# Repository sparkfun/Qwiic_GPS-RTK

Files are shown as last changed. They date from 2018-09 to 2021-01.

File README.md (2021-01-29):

SparkFun Ublox GPS-RTK (Qwiic) - NEO-M8P-2
===========================================================

SparkFun GPS-RTK - NEO-M8P-2 (https://www.sparkfun.com/products/15005)

[*SparkFun GPS-RTK - NEO-M8P-2 (GPS-15005)*](https://www.sparkfun.com/products/15005)

The NEO-M8P-2 module is the top-of-the-line module for high accuracy GNSS and GPS location solutions including RTK. The NEO-M8P-2 is unique in that it is capable of both rover and base station operations. The ‘-2’ designation means this module has survey-in mode allowing the module to become a base station and produce RTCM 3.x correction data. 

Repository Contents
-------------------

* **/Documents** - Ublox datasheets and various whitepapers around RTK
* **/Hardware** - Eagle files

Documentation
--------------

* **[Installing an Arduino Library Guide](https://learn.sparkfun.com/tutorials/installing-an-arduino-library)** - Basic information on how to install an Arduino library.
* **[Arduino Library](https://github.com/sparkfun/SparkFun_u-blox_GNSS_Arduino_Library)** - Arduino Library for the SparkFun Ublox GPS-RTK.
* **[Hookup Guide](https://learn.sparkfun.com/tutorials/gps-rtk-hookup-guide)** - Basic hookup guide for the SparkFun Ublox GPS-RTK.

Product Versions
----------------
* [GPS-15005](https://www.sparkfun.com/products/15005) - SparkFun Red
* [SPX-14980](https://www.sparkfun.com/products/14980) - SparkX Black

License Information
-------------------

This product is _**open source**_! 

Various bits of the code have different licenses applied. Anything SparkFun wrote is beerware; if you see me (or any other SparkFun employee) at the local, and you've found our code helpful, please buy us a round!

Please use, reuse, and modify these files as you see fit. Please maintain attribution to SparkFun Electronics and release anything derivative under the same license.

Distributed as-is; no warranty is given.

- Your friends at SparkFun.

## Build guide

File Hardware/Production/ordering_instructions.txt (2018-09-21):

panel size, 96x88mm
PCB thickness, 1.6mm
number of layers, 2
soldermask color, Red
silkscreen color, White
oz copper, 1oz
finish, HASL lead free
stencils, top
pcs per panel, 4

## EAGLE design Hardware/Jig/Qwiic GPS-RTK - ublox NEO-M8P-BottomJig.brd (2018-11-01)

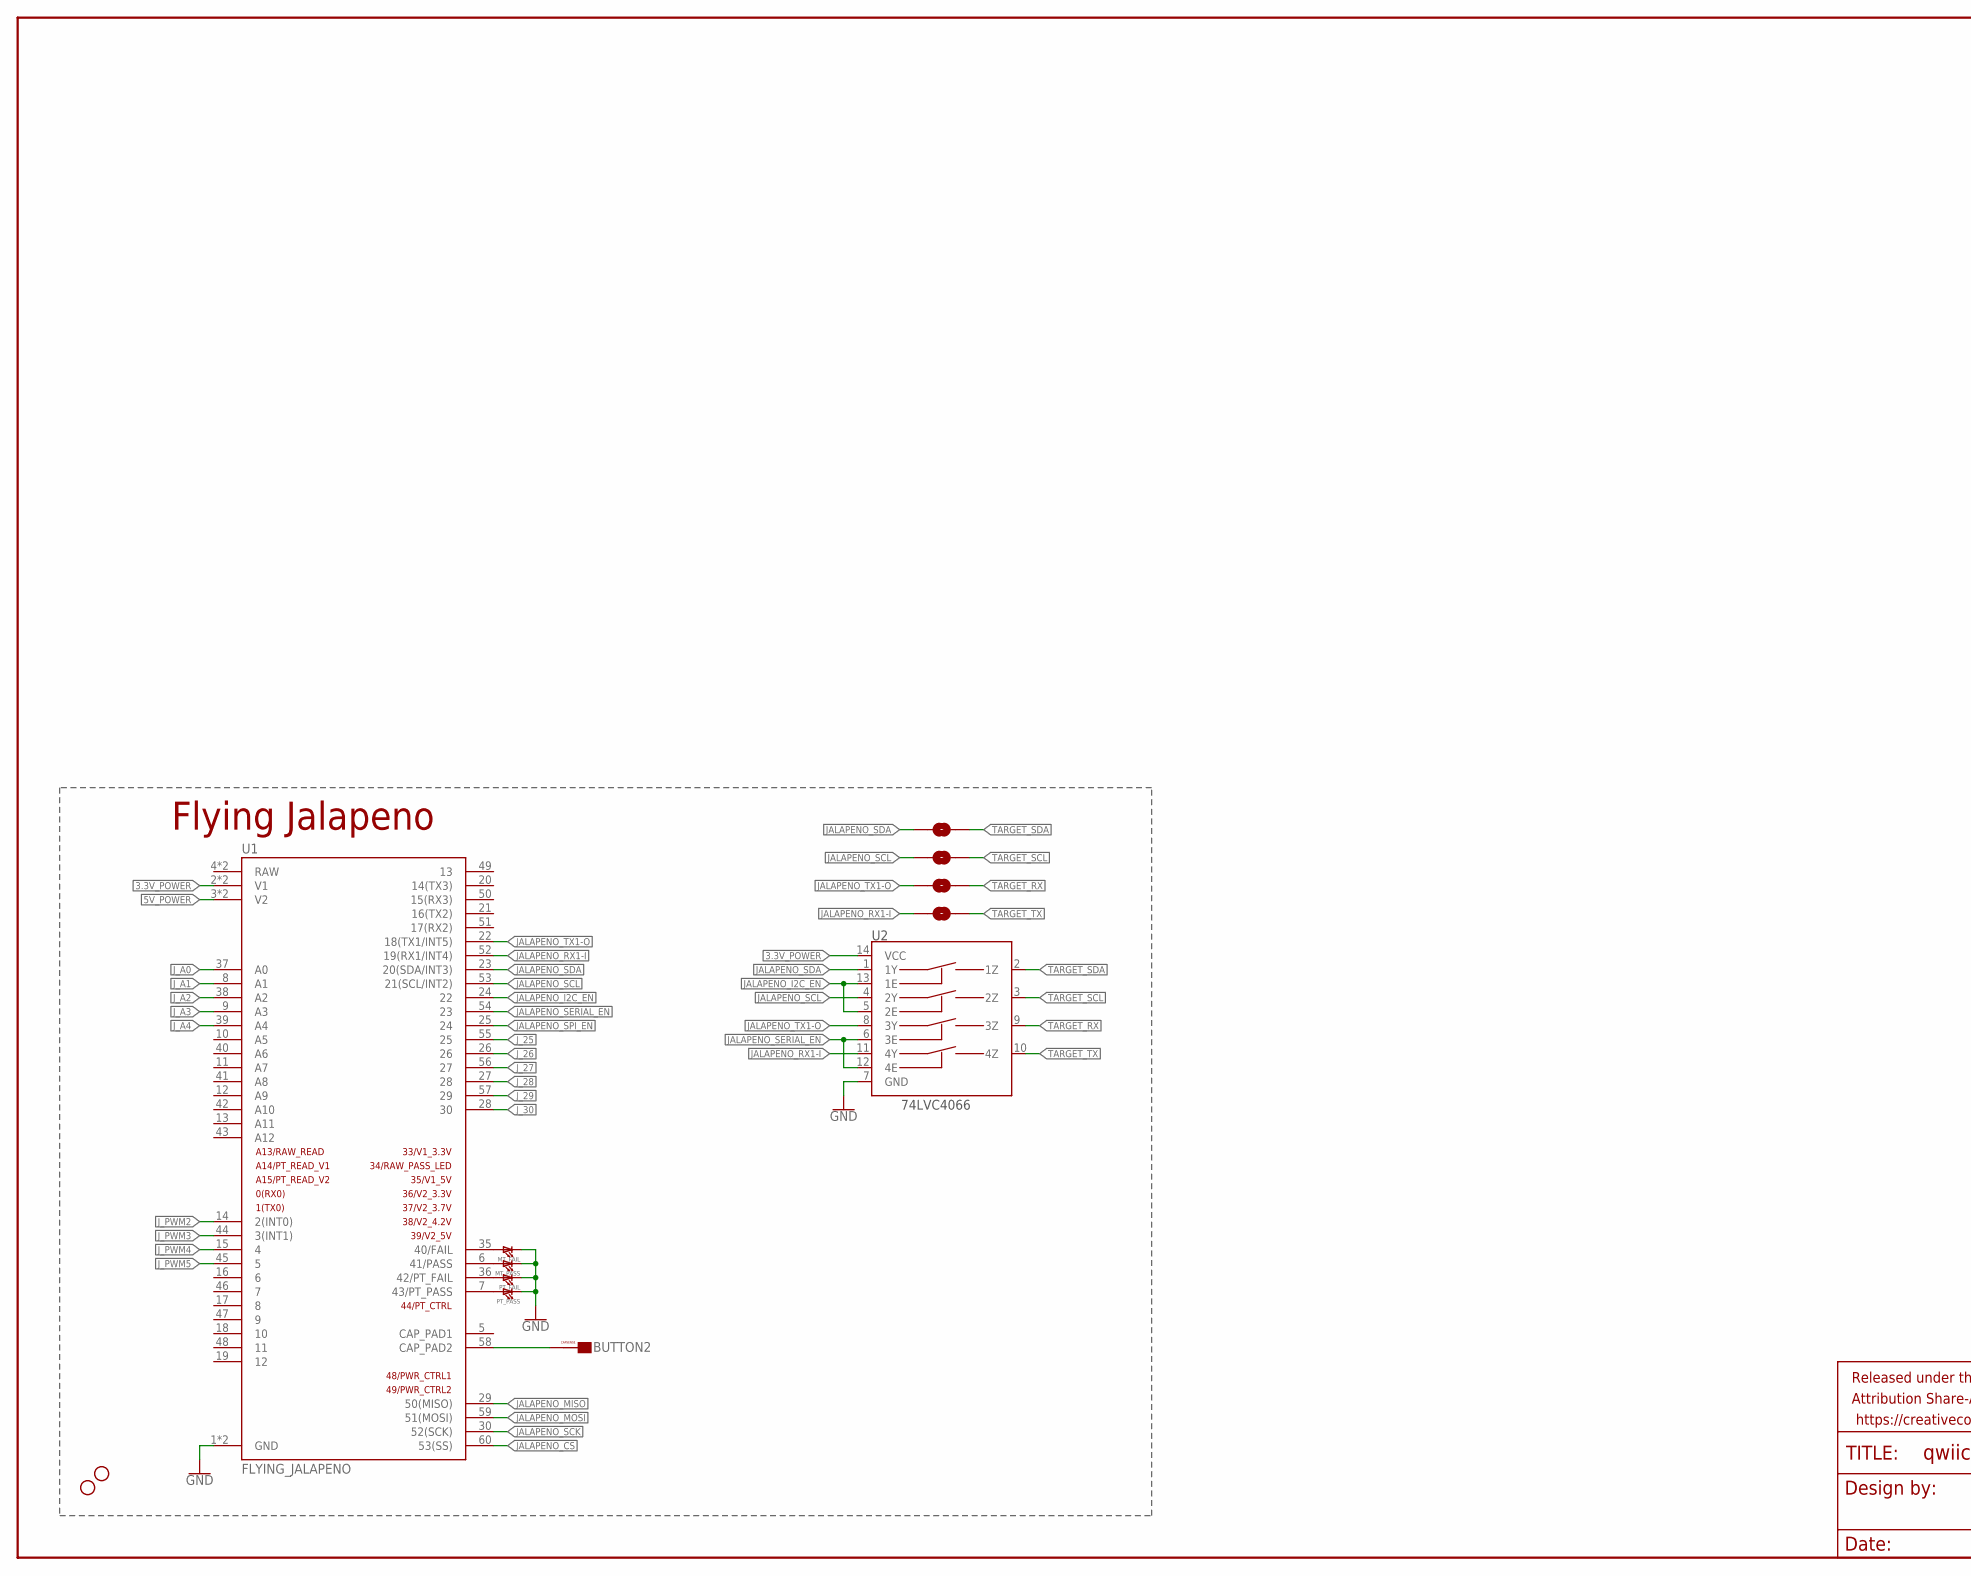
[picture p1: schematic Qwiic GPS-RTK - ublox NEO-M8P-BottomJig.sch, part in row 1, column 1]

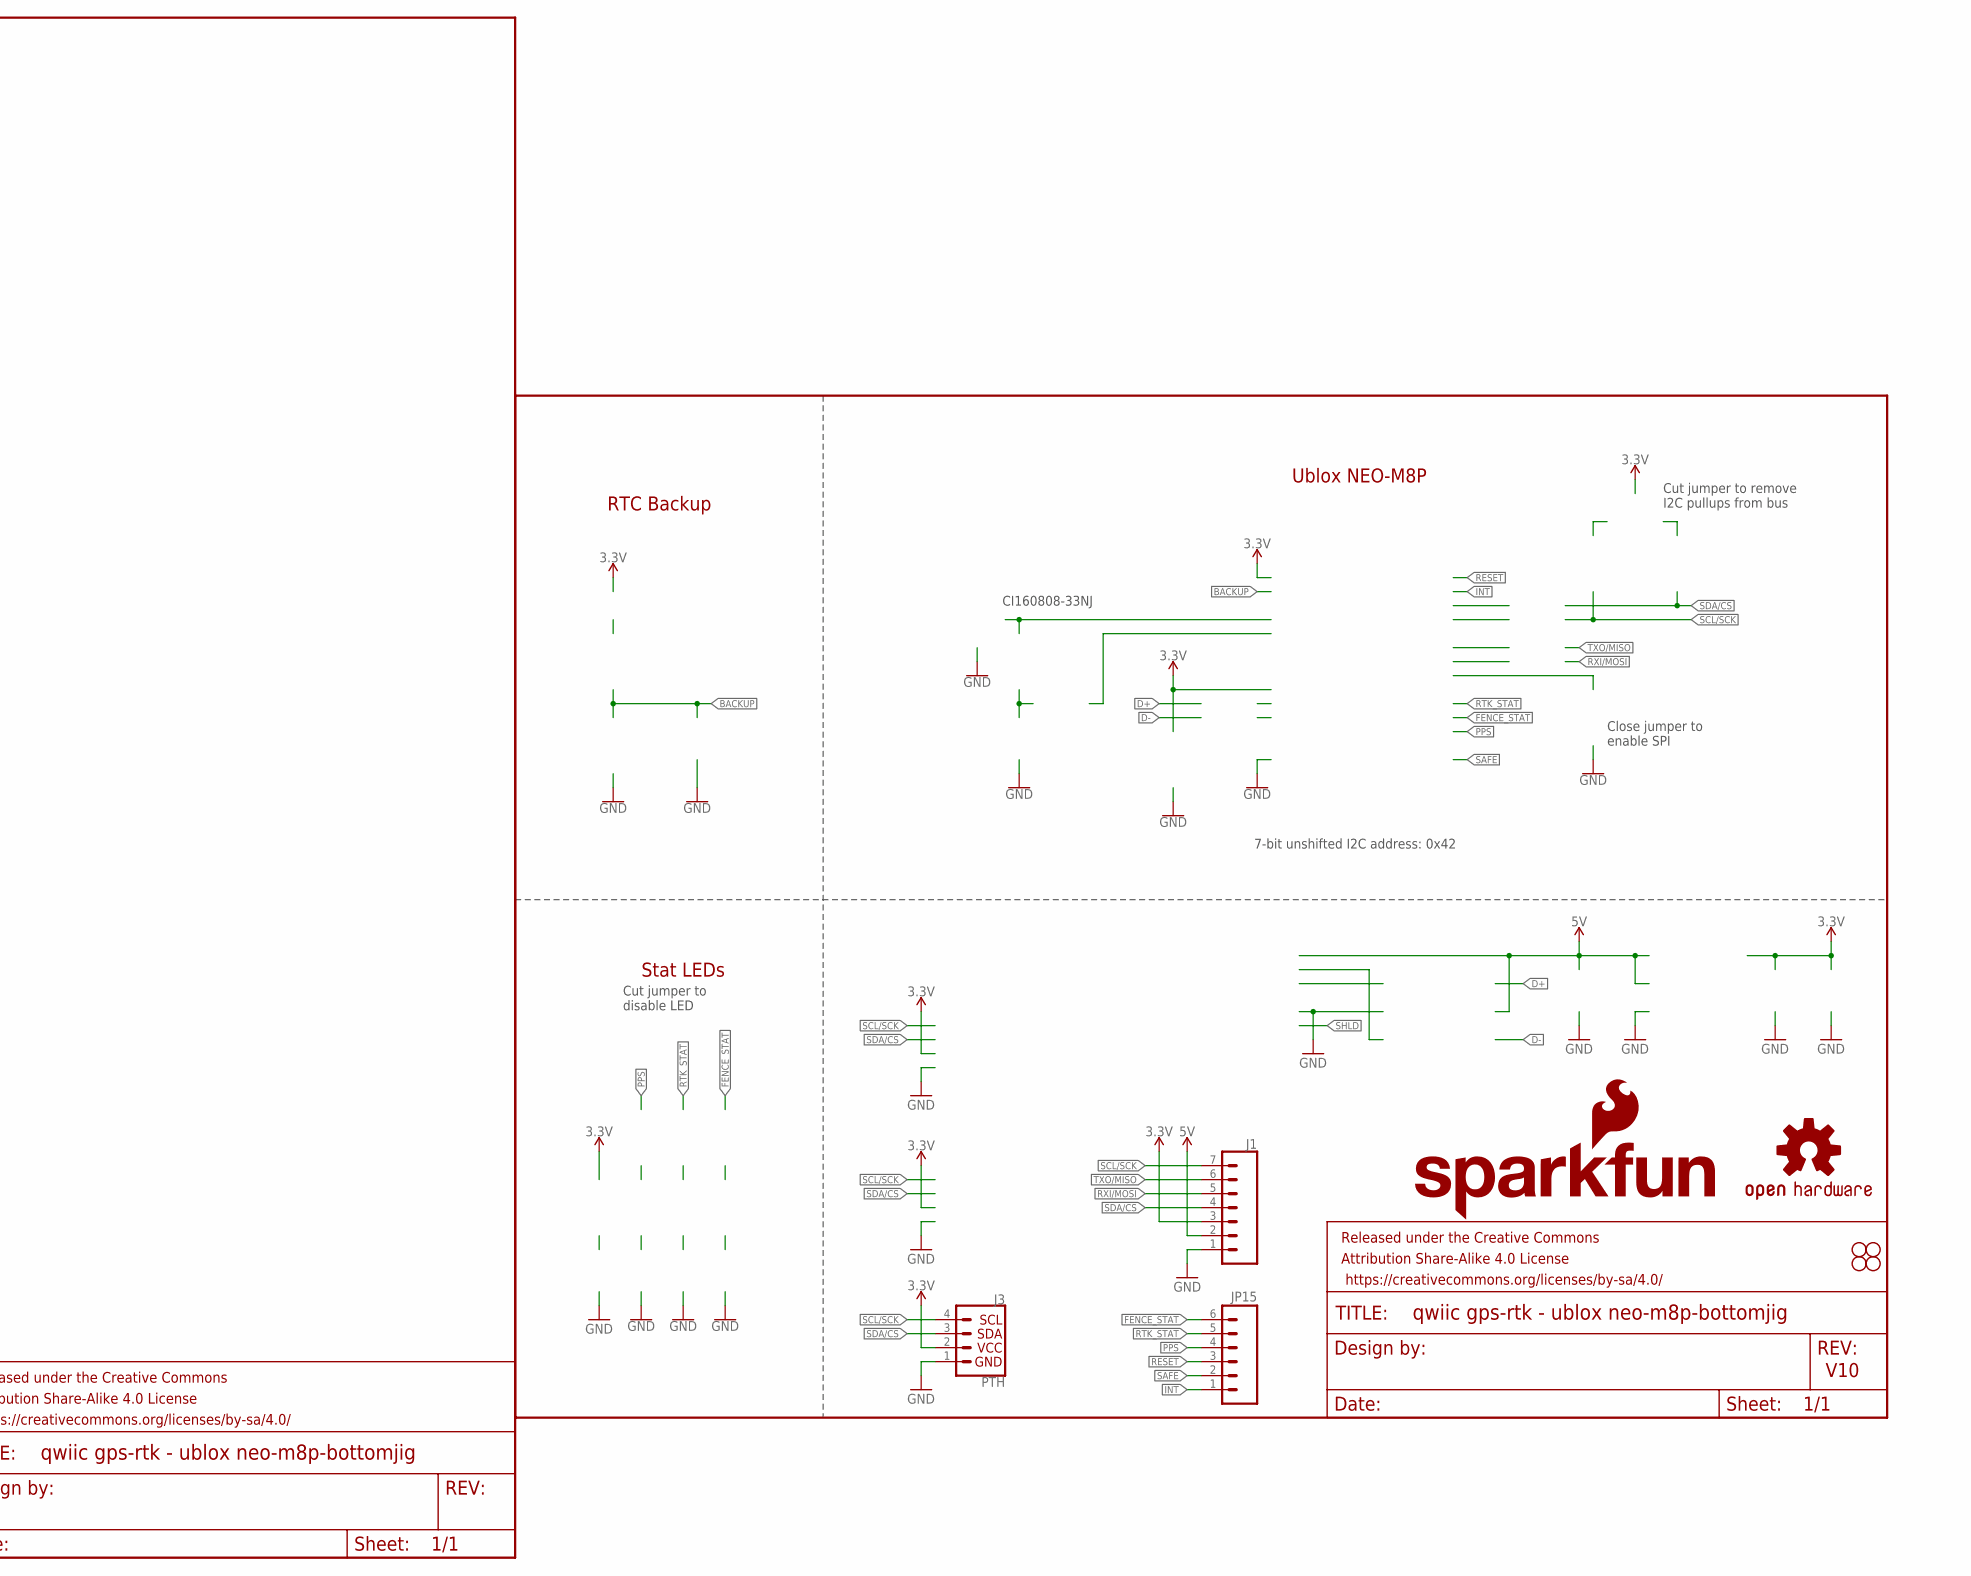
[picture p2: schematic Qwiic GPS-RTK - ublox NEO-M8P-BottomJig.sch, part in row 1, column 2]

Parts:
BUTTON2: CAPSENSE_BUTTON_PAD_ONLY; CAPSENSE_BUTTON_PADS_ONLY
FRAME1: FRAME-LETTER; CREATIVE_COMMONS
FRAME2: FRAME-LEDGER; CREATIVE_COMMONS
H1, H3: STAND-OFF
J1: CONN_07NO_SILK; 1X07_NO_SILK
J3: PTH; 1X04_NO_SILK
JP15: M06NO_SILK_FEMALE_PTH; 1X06_NO_SILK
JP31, JP41, JP91, JP101: STAND-OFF
J_SCL, J_SCL1, J_SCL2: JUMPER-SMT_2_NO_NO-SILK; SMT-JUMPER_2_NO_NO-SILK
J_SDA: JUMPER-SMT_2_NO_NO-SILK; SMT-JUMPER_2_NO_NO-SILK
LOGO1: OSHW-LOGOMINI; OSHW-LOGO-MINI
LOGO2: SFE_LOGO_NAME_FLAME.1_INCH; SFE_LOGO_NAME_FLAME_.1
MT_FAIL: LED1206; LED-1206
MT_PASS: LED1206; LED-1206
PT_FAIL: LED1206; LED-1206
PT_PASS: LED1206; LED-1206
U1: FLYING_JALAPENO; FLYING_JALAPENO_V3_M
U2: 74LVC4066; SO14

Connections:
3.3V: J1.3, J3.2 (VCC)
3.3V_POWER: U1.2 (V1), U1.32 (V1), U2.14 (VCC)
5V: J1.2
5V_POWER: U1.3 (V2), U1.33 (V2)
!RESET: JP15.3
!SAFE: JP15.2
BUTTON2: BUTTON2.CAPSENSE_PAD, U1.58 (CAP_PAD2)
FENCE_STAT: JP15.6
GND: J1.1, J3.1 (GND), MT_FAIL.C, MT_PASS.C, PT_FAIL.C, PT_PASS.C, U1.1 (GND), U1.31 (GND), U2.7 (GND)
INT: JP15.1
JALAPENO_CS: U1.60 (53(SS))
JALAPENO_I2C_EN: U1.24 (22), U2.5 (2E), U2.13 (1E)
JALAPENO_MISO: U1.29 (50(MISO))
JALAPENO_MOSI: U1.59 (51(MOSI))
JALAPENO_RX1-I: J_SDA.1, U1.52 (19(RX1/INT4)), U2.11 (4Y)
JALAPENO_SCK: U1.30 (52(SCK))
JALAPENO_SCL: J_SCL.1, U1.53 (21(SCL/INT2)), U2.4 (2Y)
JALAPENO_SDA: J_SCL2.1, U1.23 (20(SDA/INT3)), U2.1 (1Y)
JALAPENO_SERIAL_EN: U1.54 (23), U2.6 (3E), U2.12 (4E)
JALAPENO_SPI_EN: U1.25 (24)
JALAPENO_TX1-O: J_SCL1.1, U1.22 (18(TX1/INT5)), U2.8 (3Y)
J_25: U1.55 (25)
J_26: U1.26
J_27: U1.56 (27)
J_28: U1.27 (28)
J_29: U1.57 (29)
J_30: U1.28 (30)
J_A0: U1.37 (A0)
J_A1: U1.8 (A1)
J_A2: U1.38 (A2)
J_A3: U1.9 (A3)
J_A4: U1.39 (A4)
J_PWM2: U1.14 (2(INT0))
J_PWM3: U1.44 (3(INT1))
J_PWM4: U1.15 (4)
J_PWM5: U1.45 (5)
unnamed: PT_PASS.A, U1.7 (43/PT_PASS)
unnamed: PT_FAIL.A, U1.36 (42/PT_FAIL)
unnamed: MT_PASS.A, U1.6 (41/PASS)
unnamed: MT_FAIL.A, U1.35 (40/FAIL)
PPS: JP15.4
RTK_STAT: JP15.5
RXI/MOSI: J1.5
SCL/SCK: J1.7, J3.4 (SCL)
SDA/!CS: J1.4, J3.3 (SDA)
TARGET_RX: J_SCL1.2, U2.9 (3Z)
TARGET_SCL: J_SCL.2, U2.3 (2Z)
TARGET_SDA: J_SCL2.2, U2.2 (1Z)
TARGET_TX: J_SDA.2, U2.10 (4Z)
TXO/MISO: J1.6

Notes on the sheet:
V10
7-bit unshifted I2C address: 0x42
Ublox NEO-M8P
RTC Backup
Stat LEDs
Cut jumper to remove I2C pullups from bus
Cut jumper to disable LED
Close jumper to enable SPI
CI160808-33NJ
Flying Jalapeno

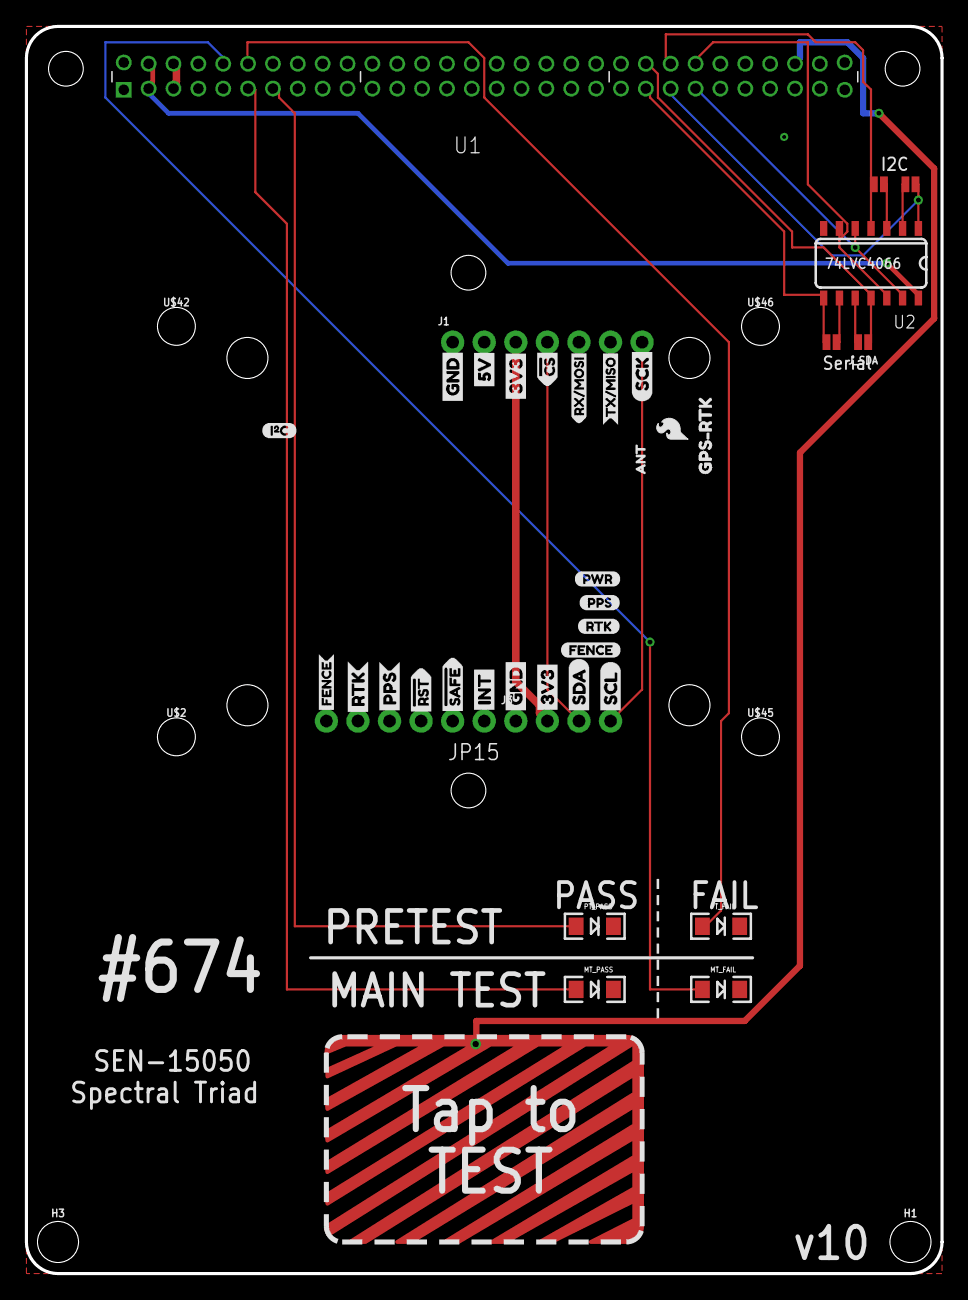
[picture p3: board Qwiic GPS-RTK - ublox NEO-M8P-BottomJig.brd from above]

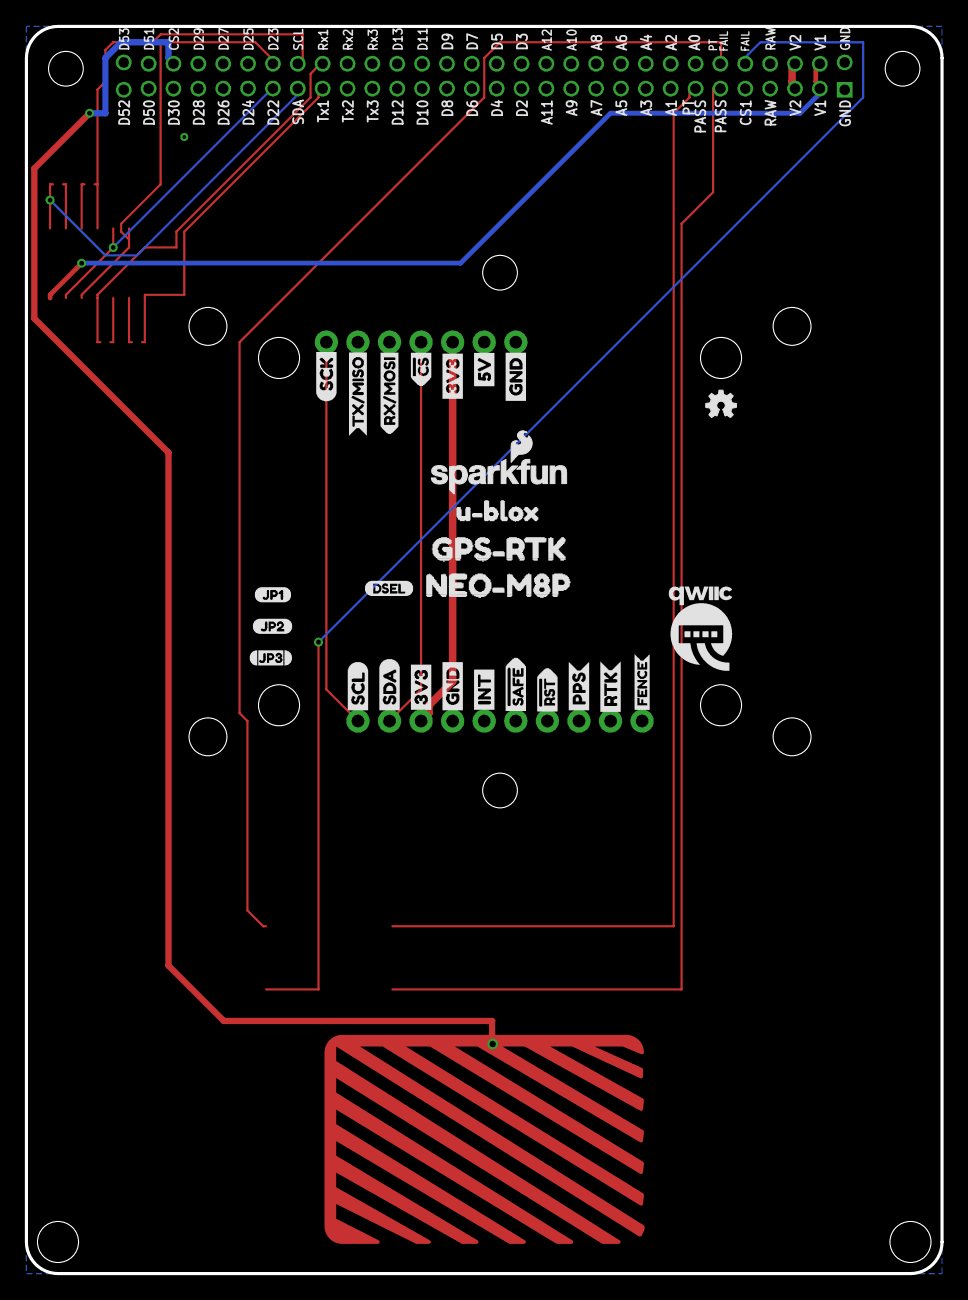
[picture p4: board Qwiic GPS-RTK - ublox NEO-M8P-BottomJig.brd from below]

Board: 2 copper layers, 73.7 x 100.3 mm, 80 parts (27 on the bottom side), 21 nets.

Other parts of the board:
U$1, U$4: SDA-[)
U$2, U$42, U$45, U$46: STAND-OFF-TIGHT
U$3, U$5: SCL-[)
U$6, U$7, U$60, U$61: 3V3-04
U$8, U$9, U$62, U$63: GND-04
U$10: I_SUPER2_C-()-03
U$11: FENCE2
U$12: JP20
U$13, U$28, U$29: RTK1
U$14, U$17: FENCE0
U$15, U$16: INT8
U$18: PWR-()-03
U$19, U$20: 5V
U$21: GPS#RTK0
U$22: U#BLOX3
U$23, U$24: CS#-<]
U$25: JP10
U$26: RX#MOSI2
U$27: DSEL0
U$30: QWIIC-LOGO-MEDIUM
U$31: RX#MOSI3
U$32: JP32
U$33: SFE_LOGO_FLAME_.1
U$34: TX#MISO0
U$35, U$36: #RST3
U$37: TX#MISO1
U$38, U$41: SCK-(]-04
U$39, U$40: #SAFE1
U$43, U$44: PPS5
U$47, U$48: NUBBIN_LOCKER
U$52: PPS0
U$53: NEO#M8P3
U$54: GPS#RTK1
U$55: ANT0

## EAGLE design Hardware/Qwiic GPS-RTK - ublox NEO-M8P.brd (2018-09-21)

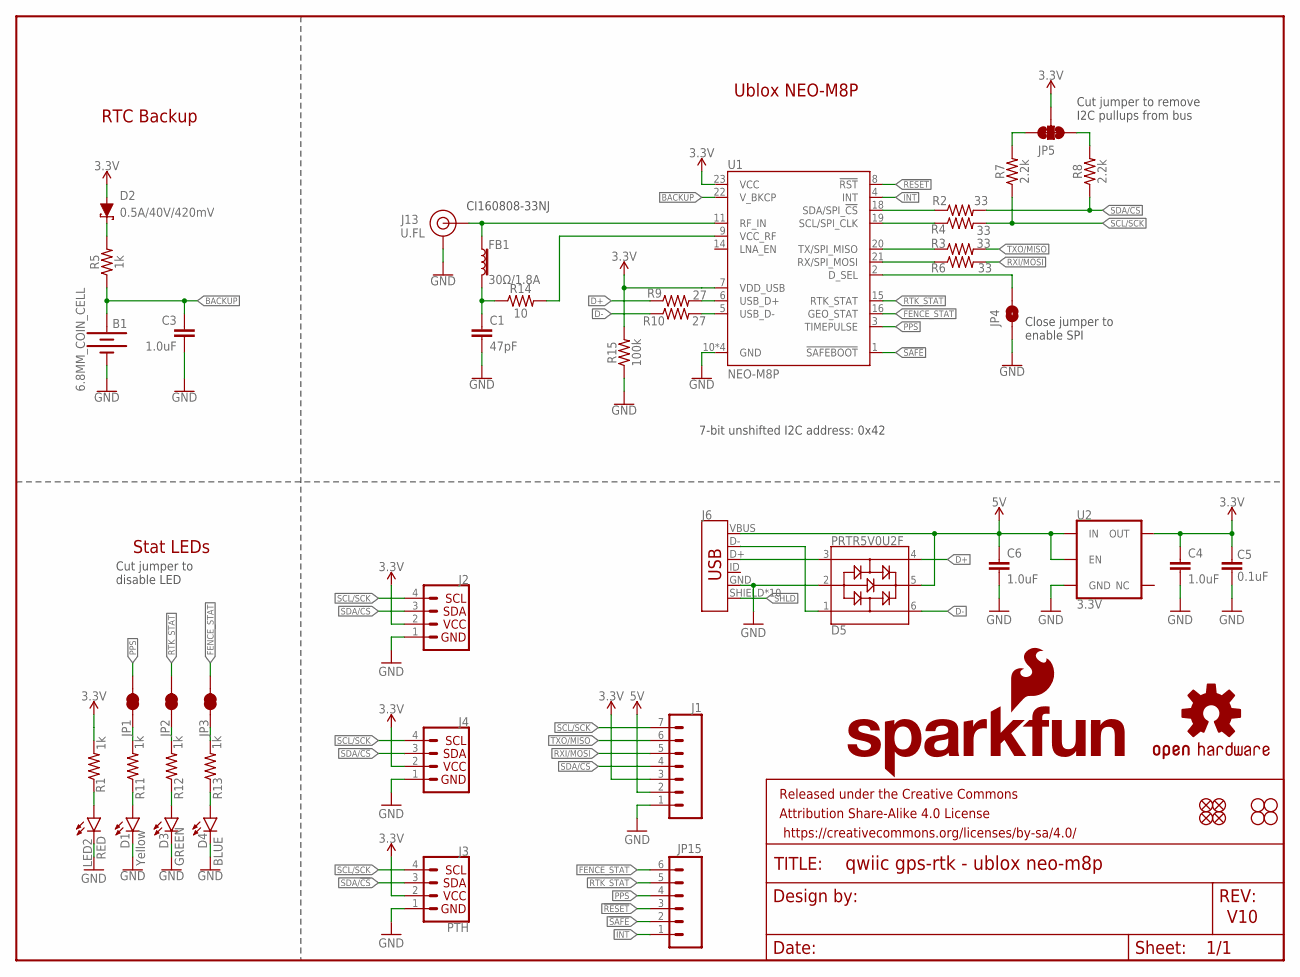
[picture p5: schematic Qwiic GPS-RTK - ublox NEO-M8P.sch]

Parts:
B1: 6.8MM_COIN_CELL; BATTCON-6.8MM
C1: 47pF; 0603
C3, C4, C6: 1.0uF; 0603
C5: 0.1uF; 0603
D1: Yellow; LED-0603
D2: 0.5A/40V/420mV; SOD-323
D3: GREEN; LED-0603
D4: BLUE; LED-0603
D5: PRTR5V0U2F; SOT886
FB1: 30Ω/1.8A; 0603
FRAME1: FRAME-LETTER; CREATIVE_COMMONS
J1: CONN_07NO_SILK; 1X07_NO_SILK
J2, J4: I2C_STANDARDQWIIC; 1X04_1MM_RA
J3: PTH; 1X04_NO_SILK
J6: USB_MICRO-B_HALF_PTH_MILL; USB-MICROB-PTH-MILL
J13: U.FL
JP1, JP2, JP3: JUMPER-SMT_2_NC_TRACE_SILK; SMT-JUMPER_2_NC_TRACE_SILK
JP4: JUMPER-SMT_2_NO_SILK; SMT-JUMPER_2_NO_SILK
JP5: JUMPER-SMT_3_2-NC_TRACE_SILK; SMT-JUMPER_3_2-NC_TRACE_SILK
JP15: M06NO_SILK_FEMALE_PTH; 1X06_NO_SILK
JP21, JP61, JP71, JP81: FIDUCIALUFIDUCIAL; MICRO-FIDUCIAL
JP31, JP41, JP91, JP101: STAND-OFF
LED2: RED; LED-0603
LOGO1: OSHW-LOGOMINI; OSHW-LOGO-MINI
LOGO2: SFE_LOGO_NAME_FLAME.1_INCH; SFE_LOGO_NAME_FLAME_.1
R1, R5, R11, R12, R13: 1k; 0603
R2, R3, R4, R6: 33; 0603
R7, R8: 2.2k; 0603
R9, R10: 27; 0603
R14: 10; 0603
R15: 100k; 0603
U1: NEO-M8P
U2: 3.3V; SOT23-5

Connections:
3.3V: C4.1, C5.2, D2.A, J1.3, J2.2, J3.2 (VCC), J4.2, JP5.2, R1.2, R15.2, U1.7 (VDD_USB), U1.23 (VCC), U2.5 (OUT)
5V: C6.1, D5.5, J1.2, J6.VBUS, U2.1 (IN), U2.3 (EN)
!RESET: JP15.3, U1.8 (!RST)
!SAFE: JP15.2, U1.1 (!SAFEBOOT!)
ANT_VCC: C1.1, FB1.2, R14.1
BACKUP: B1.+, C3.1, R5.1, U1.22 (V_BKCP)
D+: D5.4, R9.1
D-: D5.6, R10.1
D_SEL: JP4.2, U1.2 (D_SEL)
FENCE_STAT: JP3.2, JP15.6, U1.16 (GEO_STAT)
GND: B1.-, C1.2, C3.2, C4.2, C5.1, C6.2, D1.C, D3.C, D4.C, D5.2, J1.1, J2.1, J3.1 (GND), J4.1, J6.GND, J13.1 (GND), J13.2 (GND), JP4.1, LED2.C, R15.1, U1.10 (GND), U1.12 (GND), U1.13 (GND), U1.24 (GND), U2.2 (GND)
GPS_ANT1: FB1.1, J13.FEED (SIGNAL), U1.11 (RF_IN)
INT: JP15.1, U1.4 (INT)
unnamed: D3.A, R12.1
unnamed: D1.A, R11.1
unnamed: JP2.1, R12.2
unnamed: JP1.1, R11.2
unnamed: JP5.1, R8.2
unnamed: D2.C, R5.2
unnamed: D4.A, R13.1
unnamed: JP5.3, R7.2
unnamed: JP3.1, R13.2
unnamed: LED2.A, R1.1
unnamed: R9.2, U1.6 (USB_D+)
unnamed: R10.2, U1.5 (USB_D-)
unnamed: R14.2, U1.9 (VCC_RF)
PPS: JP1.2, JP15.4, U1.3 (TIMEPULSE)
RTK_STAT: JP2.2, JP15.5, U1.15 (RTK_STAT)
RXI/MOSI: J1.5, R6.2
RXLV: R6.1, U1.21 (RX/SPI_MOSI)
SCL/SCK: J1.7, J2.4, J3.4 (SCL), J4.4, R4.2, R7.1
SCL_LV: R4.1, U1.19 (SCL/SPI_CLK)
SDA/!CS: J1.4, J2.3, J3.3 (SDA), J4.3, R2.2, R8.1
SDA_LV: R2.1, U1.18 (SDA/SPI_!CS!)
SHLD: J6.SHIELD, J6.SHIELD2 (SHIELD), J6.SHIELD3 (SHIELD), J6.SHIELD4 (SHIELD), J6.SHIELD5 (SHIELD), J6.SHIELD6 (SHIELD), J6.SHIELD7 (SHIELD), J6.SHIELD8 (SHIELD), J6.SHIELD9 (SHIELD), J6.SHIELD10 (SHIELD)
TXLV: R3.1, U1.20 (TX/SPI_MISO)
TXO/MISO: J1.6, R3.2
USB_D+: D5.3, J6.D+
USB_D-: D5.1, J6.D-

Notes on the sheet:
V10
7-bit unshifted I2C address: 0x42
Ublox NEO-M8P
RTC Backup
Stat LEDs
Cut jumper to remove I2C pullups from bus
Cut jumper to disable LED
Close jumper to enable SPI
CI160808-33NJ

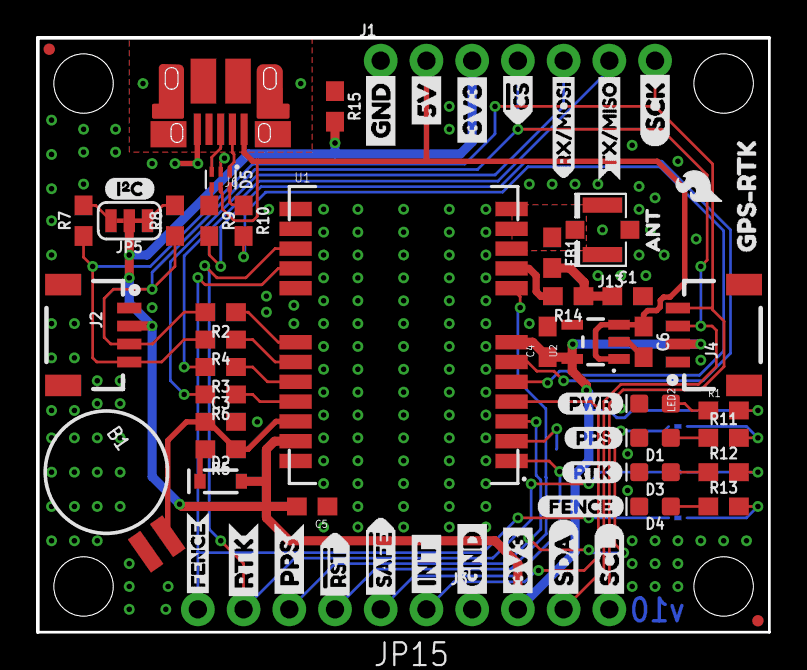
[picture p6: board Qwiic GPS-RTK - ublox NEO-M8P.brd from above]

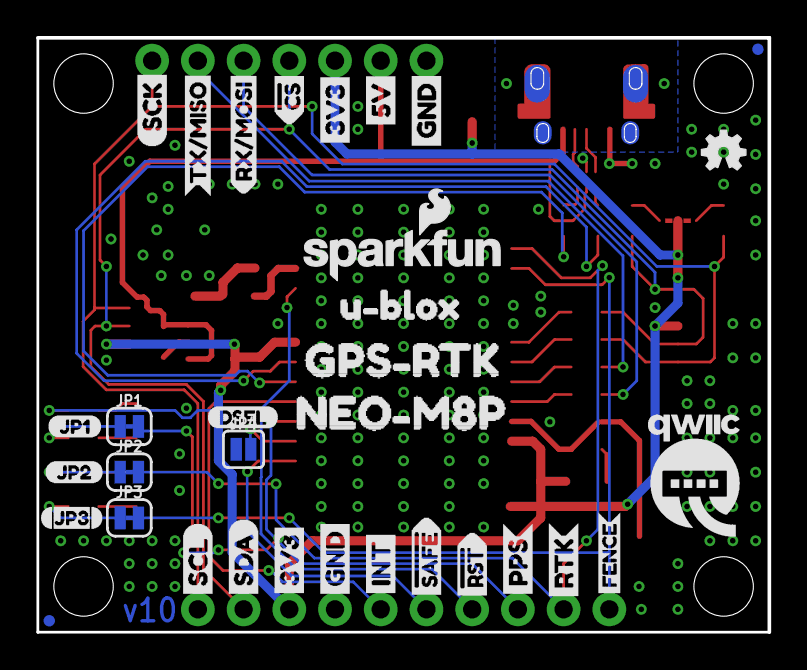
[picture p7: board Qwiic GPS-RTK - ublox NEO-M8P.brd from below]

Board: 2 copper layers, 40.6 x 33.0 mm, 103 parts (33 on the bottom side), 39 nets.

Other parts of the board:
U$1, U$4: SDA-[)
U$3, U$5: SCL-[)
U$6, U$7, U$60, U$61: 3V3-04
U$8, U$9, U$62, U$63: GND-04
U$10: I_SUPER2_C-()-03
U$11: FENCE2
U$12: JP20
U$13, U$28, U$29: RTK1
U$14, U$17: FENCE0
U$15, U$16: INT8
U$18: PWR-()-03
U$19, U$20: 5V
U$21: GPS#RTK0
U$22: U#BLOX3
U$23, U$24: CS#-<]
U$25: JP10
U$26: RX#MOSI2
U$27: DSEL0
U$30: QWIIC-LOGO-MEDIUM
U$31: RX#MOSI3
U$32: JP32
U$33: SFE_LOGO_FLAME_.1
U$34: TX#MISO0
U$35, U$36: #RST3
U$37: TX#MISO1
U$38, U$41: SCK-(]-04
U$39, U$40: #SAFE1
U$43, U$44: PPS5
U$52: PPS0
U$53: NEO#M8P3
U$54: GPS#RTK1
U$55: ANT0

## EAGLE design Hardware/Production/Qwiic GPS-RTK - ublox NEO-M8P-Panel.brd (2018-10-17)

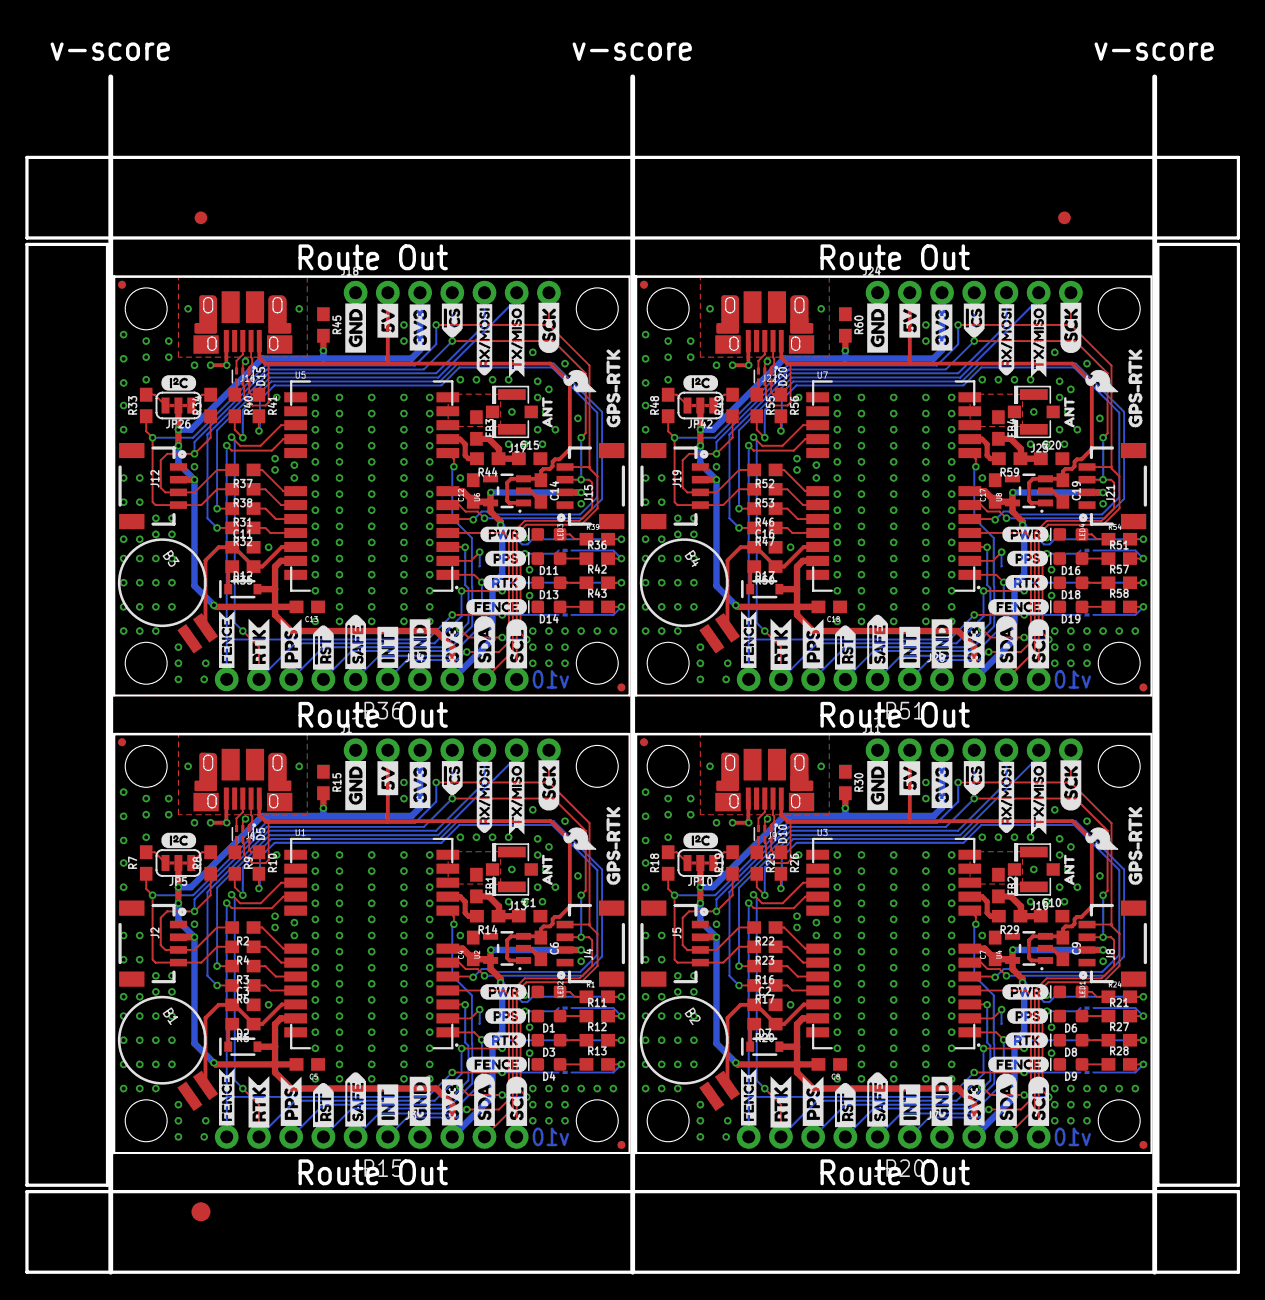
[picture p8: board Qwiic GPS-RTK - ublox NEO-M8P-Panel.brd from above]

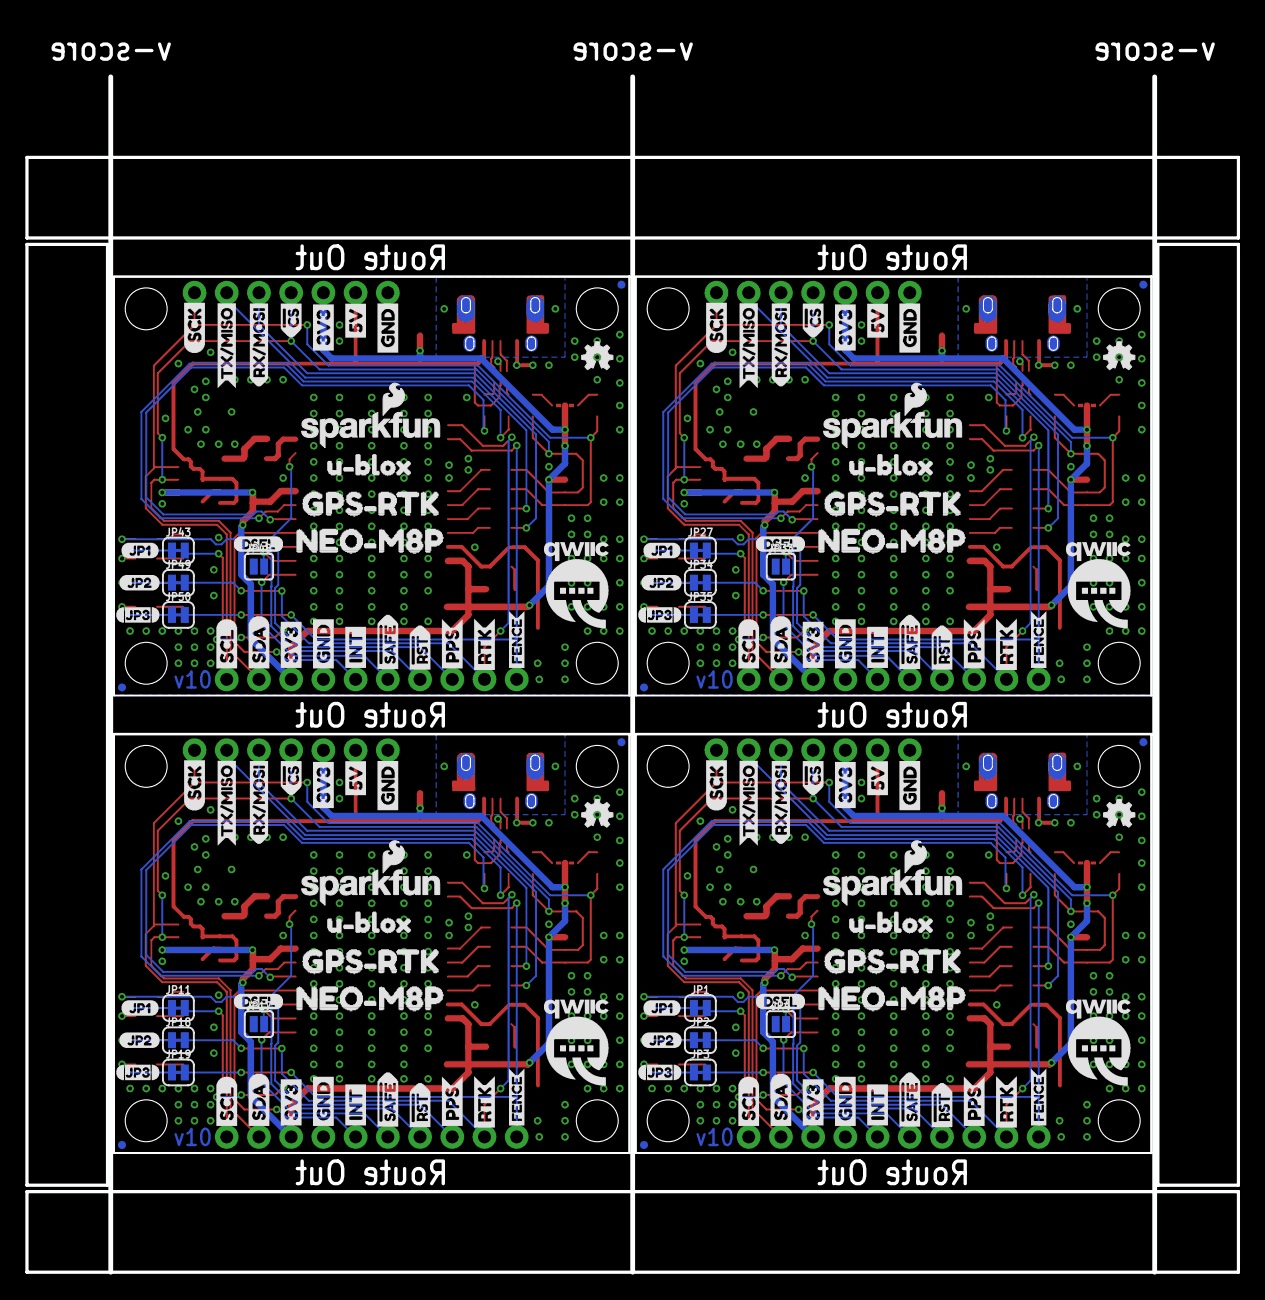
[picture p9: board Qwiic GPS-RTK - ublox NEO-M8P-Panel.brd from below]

Board: 2 copper layers, 95.5 x 94.2 mm, 411 parts (132 on the bottom side), 156 nets.

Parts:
B1, B2, B3, B4: 6.8MM_COIN_CELL; BATTCON-6.8MM
C1, C10, C15, C20: 47pF; 0603
C2, C3, C4, C6, C7, C9, C11, C12, C14, C16, C17, C19: 1.0uF; 0603
C5, C8, C13, C18: 0.1uF; 0603
D1, D6, D11, D16: Yellow; LED-0603
D2, D7, D12, D17: 0.5A/40V/420mV; SOD-323
D3, D8, D13, D18: GREEN; LED-0603
D4, D9, D14, D19: BLUE; LED-0603
D5, D10, D15, D20: PRTR5V0U2F; SOT886
E$1, E$2: FIDUCIAL-1X2
E$3: FIDUCIAL-1.5X3
FB1, FB2, FB3, FB4: 30Ω/1.8A; 0603
J1, J11, J18, J24: 1X07_NO_SILK
J2, J4, J5, J8, J12, J15, J19, J21: 1X04_1MM_RA
J3, J7, J14, J20: PTH; 1X04_NO_SILK
J6, J9, J16, J22: USB-MICROB-PTH-MILL
J10, J13, J17, J23: U.FL
JP1, JP2, JP3, JP11, JP18, JP19, JP27, JP34, JP35, JP43, JP49, JP50: SMT-JUMPER_2_NC_TRACE_SILK
JP4, JP17, JP33, JP48: SMT-JUMPER_2_NO_SILK
JP5, JP10, JP26, JP42: SMT-JUMPER_3_2-NC_TRACE_SILK
JP6, JP7, JP14, JP16, JP22, JP23, JP30, JP31, JP32, JP37, JP38, JP41, JP46, JP47, JP91, JP101: STAND-OFF
JP8, JP9, JP12, JP13, JP21, JP24, JP25, JP28, JP29, JP39, JP40, JP44, JP45, JP61, JP71, JP81: FIDUCIALUFIDUCIAL; MICRO-FIDUCIAL
JP15, JP20, JP36, JP51: 1X06_NO_SILK
LED1, LED2, LED3, LED4: RED; LED-0603
LOGO1, LOGO3, LOGO5, LOGO7: OSHW-LOGOMINI; OSHW-LOGO-MINI
LOGO2, LOGO4, LOGO6, LOGO8: SFE_LOGO_NAME_FLAME.1_INCH; SFE_LOGO_NAME_FLAME_.1
R1, R5, R11, R12, R13, R20, R21, R24, R27, R28, R35, R36, R39, R42, R43, R50, R51, R54, R57, R58: 1k; 0603
R2, R3, R4, R6, R16, R17, R22, R23, R31, R32, R37, R38, R46, R47, R52, R53: 33; 0603
R7, R8, R18, R19, R33, R34, R48, R49: 2.2k; 0603
R9, R10, R25, R26, R40, R41, R55, R56: 27; 0603
R14, R29, R44, R59: 10; 0603
R15, R30, R45, R60: 100k; 0603
U1, U3, U5, U7: NEO-M8P
U2, U4, U6, U8: 3.3V; SOT23-5
U$1, U$2, U$4, U$45, U$101, U$103, U$151, U$153: SDA-[)
U$3, U$5, U$42, U$46, U$102, U$104, U$152, U$154: SCL-[)
U$6, U$7, U$47, U$48, U$60, U$61, U$78, U$79, U$105, U$106, U$128, U$129, U$155, U$156, U$178, U$179: 3V3-04
U$8, U$9, U$49, U$50, U$62, U$63, U$80, U$81, U$107, U$108, U$130, U$131, U$157, U$158, U$180, U$181: GND-04
U$10, U$51, U$109, U$159: I_SUPER2_C-()-03
U$11, U$71, U$121, U$171: FENCE2
U$12, U$72, U$122, U$172: JP20
U$13, U$28, U$29, U$73, U$76, U$77, U$123, U$126, U$127, U$173, U$176, U$177: RTK1
U$14, U$17, U$74, U$75, U$124, U$125, U$174, U$175: FENCE0
U$15, U$16, U$56, U$57, U$110, U$111, U$160, U$161: INT8
U$18, U$89, U$139, U$189: PWR-()-03
U$19, U$20, U$90, U$91, U$140, U$141, U$190, U$191: 5V
U$21, U$82, U$132, U$182: GPS#RTK0
U$22, U$58, U$112, U$162: U#BLOX3
U$23, U$24, U$92, U$93, U$142, U$143, U$192, U$193: CS#-<]
U$25, U$83, U$133, U$183: JP10
U$26, U$97, U$147, U$197: RX#MOSI2
U$27, U$85, U$135, U$185: DSEL0
U$30, U$59, U$113, U$163: QWIIC-LOGO-MEDIUM
U$31, U$98, U$148, U$198: RX#MOSI3
U$32, U$84, U$134, U$184: JP32
U$33, U$96, U$146, U$196: SFE_LOGO_FLAME_.1
U$34, U$99, U$149, U$199: TX#MISO0
U$35, U$36, U$64, U$65, U$114, U$115, U$164, U$165: #RST3
U$37, U$100, U$150, U$200: TX#MISO1
U$38, U$41, U$94, U$95, U$144, U$145, U$194, U$195: SCK-(]-04
U$39, U$40, U$66, U$67, U$116, U$117, U$166, U$167: #SAFE1
U$43, U$44, U$68, U$69, U$118, U$119, U$168, U$169: PPS5
U$52, U$70, U$120, U$170: PPS0
U$53, U$86, U$136, U$186: NEO#M8P3
U$54, U$87, U$137, U$187: GPS#RTK1
U$55, U$88, U$138, U$188: ANT0

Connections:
3.3V: C4.1, C5.2, D2.A, J1.3, J2.2, J3.2, J4.2, JP5.2, R1.2, R15.2, U1.7, U1.23, U2.5
3.3V1: C7.1, C8.2, D7.A, J5.2, J7.2, J8.2, J11.3, JP10.2, R24.2, R30.2, U3.7, U3.23, U4.5
3.3V2: C12.1, C13.2, D12.A, J12.2, J14.2, J15.2, J18.3, JP26.2, R39.2, R45.2, U5.7, U5.23, U6.5
3.3V3: C17.1, C18.2, D17.A, J19.2, J20.2, J21.2, J24.3, JP42.2, R54.2, R60.2, U7.7, U7.23, U8.5
5V: C6.1, D5.5, J1.2, J6.VBUS, U2.1, U2.3
5V1: C9.1, D10.5, J9.VBUS, J11.2, U4.1, U4.3
5V2: C14.1, D15.5, J16.VBUS, J18.2, U6.1, U6.3
5V3: C19.1, D20.5, J22.VBUS, J24.2, U8.1, U8.3
!RESET: JP15.3, U1.8
!RESET1: JP20.3, U3.8
!RESET2: JP36.3, U5.8
!RESET3: JP51.3, U7.8
!SAFE: JP15.2, U1.1
!SAFE1: JP20.2, U3.1
!SAFE2: JP36.2, U5.1
!SAFE3: JP51.2, U7.1
ANT_VCC: C1.1, FB1.2, R14.1
ANT_VCC1: C10.1, FB2.2, R29.1
ANT_VCC2: C15.1, FB3.2, R44.1
ANT_VCC3: C20.1, FB4.2, R59.1
BACKUP: B1.+, C3.1, R5.1, U1.22
BACKUP1: B2.+, C2.1, R20.1, U3.22
BACKUP2: B3.+, C11.1, R35.1, U5.22
BACKUP3: B4.+, C16.1, R50.1, U7.22
D+: D5.4, R9.1
D+1: D10.4, R25.1
D+2: D15.4, R40.1
D+3: D20.4, R55.1
D-: D5.6, R10.1
D-1: D10.6, R26.1
D-2: D15.6, R41.1
D-3: D20.6, R56.1
D_SEL: JP4.2, U1.2
D_SEL1: JP17.2, U3.2
D_SEL2: JP33.2, U5.2
D_SEL3: JP48.2, U7.2
FENCE_STAT: JP3.2, JP15.6, U1.16
FENCE_STAT1: JP19.2, JP20.6, U3.16
FENCE_STAT2: JP35.2, JP36.6, U5.16
FENCE_STAT3: JP50.2, JP51.6, U7.16
GND: B1.-, C1.2, C3.2, C4.2, C5.1, C6.2, D1.C, D3.C, D4.C, D5.2, J1.1, J2.1, J3.1, J4.1, J6.GND, J13.1, J13.2, JP4.1, LED2.C, R15.1, U1.10, U1.12, U1.13, U1.24, U2.2
GND1: B2.-, C2.2, C7.2, C8.1, C9.2, C10.2, D6.C, D8.C, D9.C, D10.2, J5.1, J7.1, J8.1, J9.GND, J10.1, J10.2, J11.1, JP17.1, LED1.C, R30.1, U3.10, U3.12, U3.13, U3.24, U4.2
GND2: B3.-, C11.2, C12.2, C13.1, C14.2, C15.2, D11.C, D13.C, D14.C, D15.2, J12.1, J14.1, J15.1, J16.GND, J17.1, J17.2, J18.1, JP33.1, LED3.C, R45.1, U5.10, U5.12, U5.13, U5.24, U6.2
GND3: B4.-, C16.2, C17.2, C18.1, C19.2, C20.2, D16.C, D18.C, D19.C, D20.2, J19.1, J20.1, J21.1, J22.GND, J23.1, J23.2, J24.1, JP48.1, LED4.C, R60.1, U7.10, U7.12, U7.13, U7.24, U8.2
GPS_ANT1: FB1.1, J13.FEED, U1.11
GPS_ANT2: FB2.1, J10.FEED, U3.11
GPS_ANT3: FB3.1, J17.FEED, U5.11
GPS_ANT4: FB4.1, J23.FEED, U7.11
INT: JP15.1, U1.4
INT1: JP20.1, U3.4
INT2: JP36.1, U5.4
INT3: JP51.1, U7.4
unnamed: D3.A, R12.1
unnamed: D1.A, R11.1
unnamed: JP2.1, R12.2
unnamed: JP1.1, R11.2
unnamed: JP5.1, R8.2
unnamed: D2.C, R5.2
unnamed: D4.A, R13.1
unnamed: JP5.3, R7.2
unnamed: JP3.1, R13.2
unnamed: LED2.A, R1.1
unnamed: R9.2, U1.6
unnamed: R10.2, U1.5
unnamed: R14.2, U1.9
unnamed: JP10.1, R19.2
unnamed: JP10.3, R18.2
unnamed: D6.A, R21.1
unnamed: JP11.1, R21.2
unnamed: D7.C, R20.2
unnamed: LED1.A, R24.1
unnamed: R25.2, U3.6
unnamed: R26.2, U3.5
unnamed: D8.A, R27.1
unnamed: JP18.1, R27.2
unnamed: D9.A, R28.1
unnamed: JP19.1, R28.2
unnamed: R29.2, U3.9
unnamed: JP26.1, R34.2
unnamed: JP26.3, R33.2
unnamed: D11.A, R36.1
unnamed: JP27.1, R36.2
unnamed: D12.C, R35.2
unnamed: LED3.A, R39.1
unnamed: R40.2, U5.6
unnamed: R41.2, U5.5
unnamed: D13.A, R42.1
unnamed: JP34.1, R42.2
unnamed: D14.A, R43.1
unnamed: JP35.1, R43.2
unnamed: R44.2, U5.9
unnamed: JP42.1, R49.2
unnamed: JP42.3, R48.2
unnamed: D16.A, R51.1
unnamed: JP43.1, R51.2
unnamed: D17.C, R50.2
unnamed: LED4.A, R54.1
unnamed: R55.2, U7.6
unnamed: R56.2, U7.5
unnamed: D18.A, R57.1
unnamed: JP49.1, R57.2
unnamed: D19.A, R58.1
unnamed: JP50.1, R58.2
unnamed: R59.2, U7.9
PPS: JP1.2, JP15.4, U1.3
PPS1: JP11.2, JP20.4, U3.3
PPS2: JP27.2, JP36.4, U5.3
PPS3: JP43.2, JP51.4, U7.3
RTK_STAT: JP2.2, JP15.5, U1.15
RTK_STAT1: JP18.2, JP20.5, U3.15
RTK_STAT2: JP34.2, JP36.5, U5.15
RTK_STAT3: JP49.2, JP51.5, U7.15
RXI/MOSI: J1.5, R6.2
RXI/MOSI1: J11.5, R17.2
RXI/MOSI2: J18.5, R32.2
RXI/MOSI3: J24.5, R47.2
RXLV: R6.1, U1.21
RXLV1: R17.1, U3.21
RXLV2: R32.1, U5.21
RXLV3: R47.1, U7.21
SCL/SCK: J1.7, J2.4, J3.4, J4.4, R4.2, R7.1
SCL/SCK1: J5.4, J7.4, J8.4, J11.7, R18.1, R23.2
SCL/SCK2: J12.4, J14.4, J15.4, J18.7, R33.1, R38.2
SCL/SCK3: J19.4, J20.4, J21.4, J24.7, R48.1, R53.2
SCL_LV: R4.1, U1.19
SCL_LV1: R23.1, U3.19
SCL_LV2: R38.1, U5.19
SCL_LV3: R53.1, U7.19
SDA/!CS: J1.4, J2.3, J3.3, J4.3, R2.2, R8.1
SDA/!CS1: J5.3, J7.3, J8.3, J11.4, R19.1, R22.2
SDA/!CS2: J12.3, J14.3, J15.3, J18.4, R34.1, R37.2
SDA/!CS3: J19.3, J20.3, J21.3, J24.4, R49.1, R52.2
SDA_LV: R2.1, U1.18
SDA_LV1: R22.1, U3.18
SDA_LV2: R37.1, U5.18
SDA_LV3: R52.1, U7.18
SHLD: J6.SHIELD, J6.SHIELD2, J6.SHIELD3, J6.SHIELD4, J6.SHIELD5, J6.SHIELD6, J6.SHIELD7, J6.SHIELD8, J6.SHIELD9, J6.SHIELD10
SHLD1: J9.SHIELD, J9.SHIELD2, J9.SHIELD3, J9.SHIELD4, J9.SHIELD5, J9.SHIELD6, J9.SHIELD7, J9.SHIELD8, J9.SHIELD9, J9.SHIELD10
SHLD2: J16.SHIELD, J16.SHIELD2, J16.SHIELD3, J16.SHIELD4, J16.SHIELD5, J16.SHIELD6, J16.SHIELD7, J16.SHIELD8, J16.SHIELD9, J16.SHIELD10
SHLD3: J22.SHIELD, J22.SHIELD2, J22.SHIELD3, J22.SHIELD4, J22.SHIELD5, J22.SHIELD6, J22.SHIELD7, J22.SHIELD8, J22.SHIELD9, J22.SHIELD10
TXLV: R3.1, U1.20
TXLV1: R16.1, U3.20
TXLV2: R31.1, U5.20
TXLV3: R46.1, U7.20
TXO/MISO: J1.6, R3.2
TXO/MISO1: J11.6, R16.2
TXO/MISO2: J18.6, R31.2
TXO/MISO3: J24.6, R46.2
USB_D+: D5.3, J6.D+
USB_D+1: D10.3, J9.D+
USB_D+2: D15.3, J16.D+
USB_D+3: D20.3, J22.D+
USB_D-: D5.1, J6.D-
USB_D-1: D10.1, J9.D-
USB_D-2: D15.1, J16.D-
USB_D-3: D20.1, J22.D-

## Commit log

2018-09-11 Adding examples
    [Qwiic GPS-RTK - ublox NEO-M8P-Panel - Single.brd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]
2018-09-14 Fix schematic typo
    [Qwiic GPS-RTK - ublox NEO-M8P.brd, Qwiic GPS-RTK - ublox NEO-M8P.sch]
2018-09-16 Modifications for reds.
    [Qwiic GPS-RTK - ublox NEO-M8P-Panel.brd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]
2018-09-21 Panel update, now with route outs!
    [Qwiic GPS-RTK - ublox NEO-M8P-Panel - Single.brd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]
2018-10-17 Adding test jig
    [Qwiic GPS-RTK - ublox NEO-M8P-BottomJig.brd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]
2018-11-01 Updating test jig to one button, add ground plane.
    [Qwiic GPS-RTK - ublox NEO-M8P-BottomJig.brd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]

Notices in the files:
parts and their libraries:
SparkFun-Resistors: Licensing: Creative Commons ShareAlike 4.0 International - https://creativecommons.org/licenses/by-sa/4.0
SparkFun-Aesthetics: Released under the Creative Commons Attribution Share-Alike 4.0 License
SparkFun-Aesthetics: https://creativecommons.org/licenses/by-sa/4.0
